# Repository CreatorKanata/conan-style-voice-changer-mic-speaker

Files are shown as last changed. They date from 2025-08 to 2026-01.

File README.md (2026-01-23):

# Conan-Style Voice Changer: Bowtie Mic & Button Speaker

A real-world implementation of the iconic voice changer bowtie from Detective Conan anime.



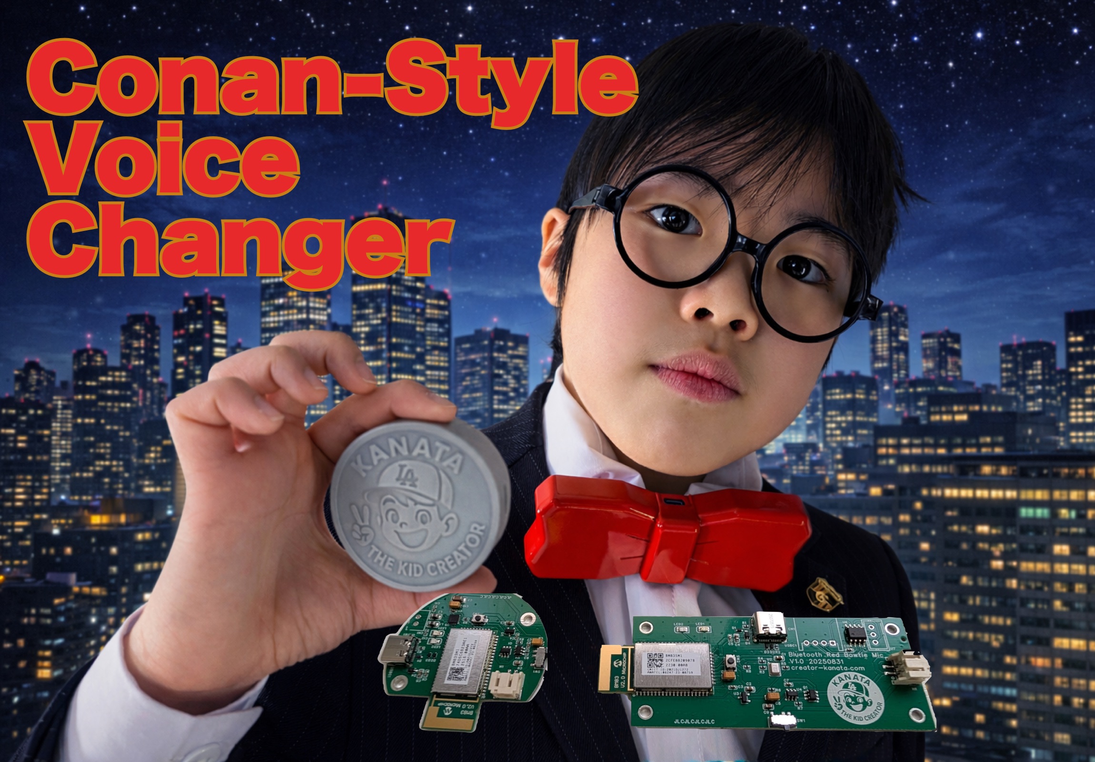
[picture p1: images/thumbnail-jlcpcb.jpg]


### Demo Video

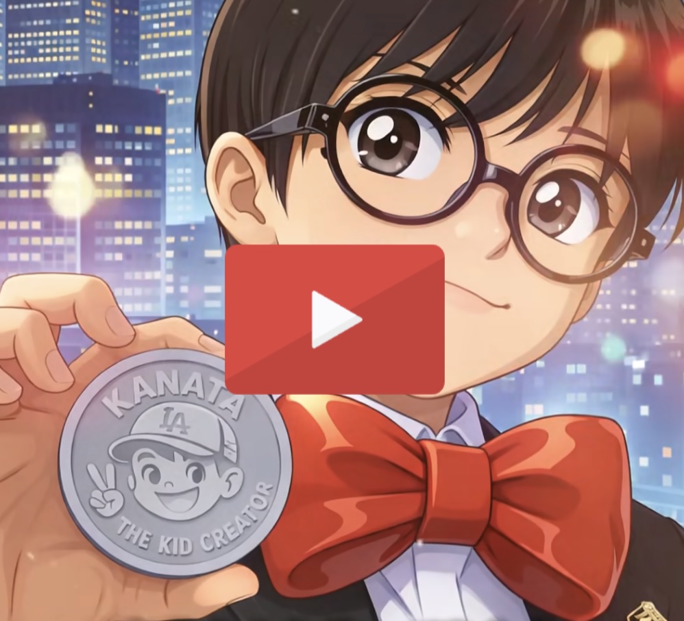
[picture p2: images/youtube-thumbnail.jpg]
Demo Video on YouTube


https://www.youtube.com/shorts/dokzC9MDHtE

### PCB Design on OSHWLab

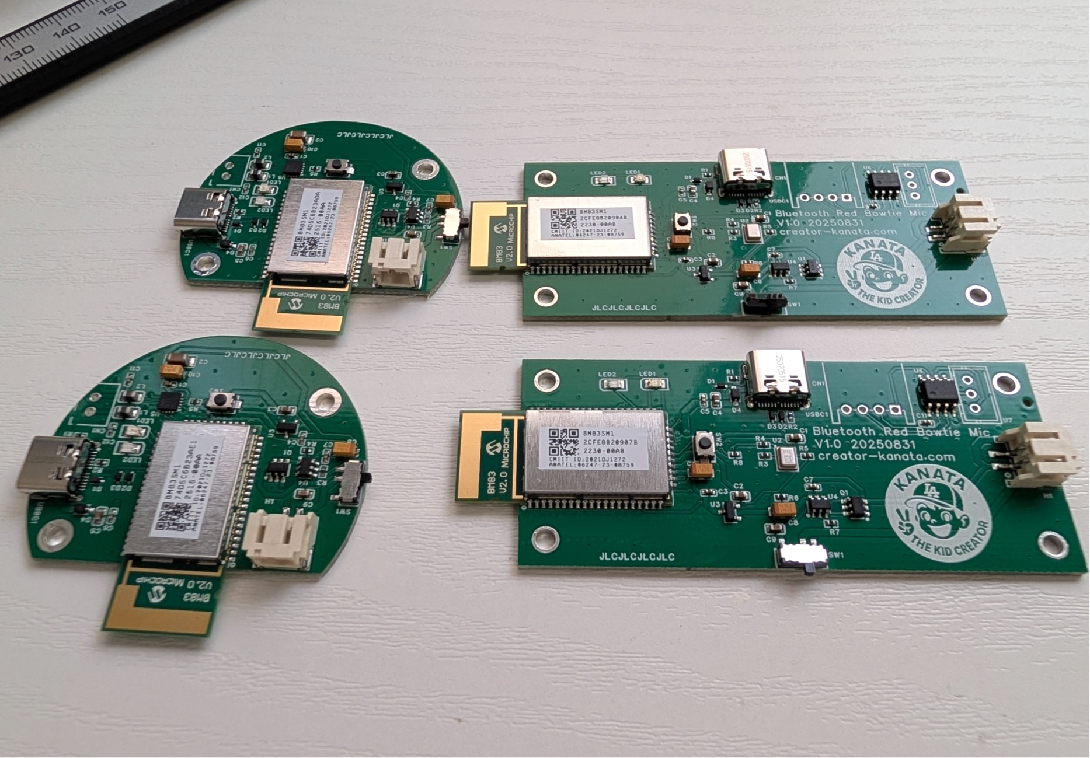
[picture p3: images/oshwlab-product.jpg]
PCB Design on OSHWLab


https://oshwlab.com/creator-kanata/conan-style-mic-speaker

## Overview

This project brings the fictional "voice changer bowtie" from Detective Conan to life. It consists of:

- **Bowtie Microphone**: A wearable microphone in the classic bowtie shape
- **Button Speaker**: A discreet speaker that can be placed anywhere
- **Raspberry Pi 5**: The processing unit that handles voice changing and translation

## Features

- **Real-time Voice Changing** using voice-changer (Beatrice)
- **Japanese to English Translation** using Gemini Live API *(planned)*
- **Wireless Operation** via Bluetooth (HFP for mic, A2DP for speaker)
- **Portable Design** with battery-powered peripherals

## Hardware

### Bowtie Microphone

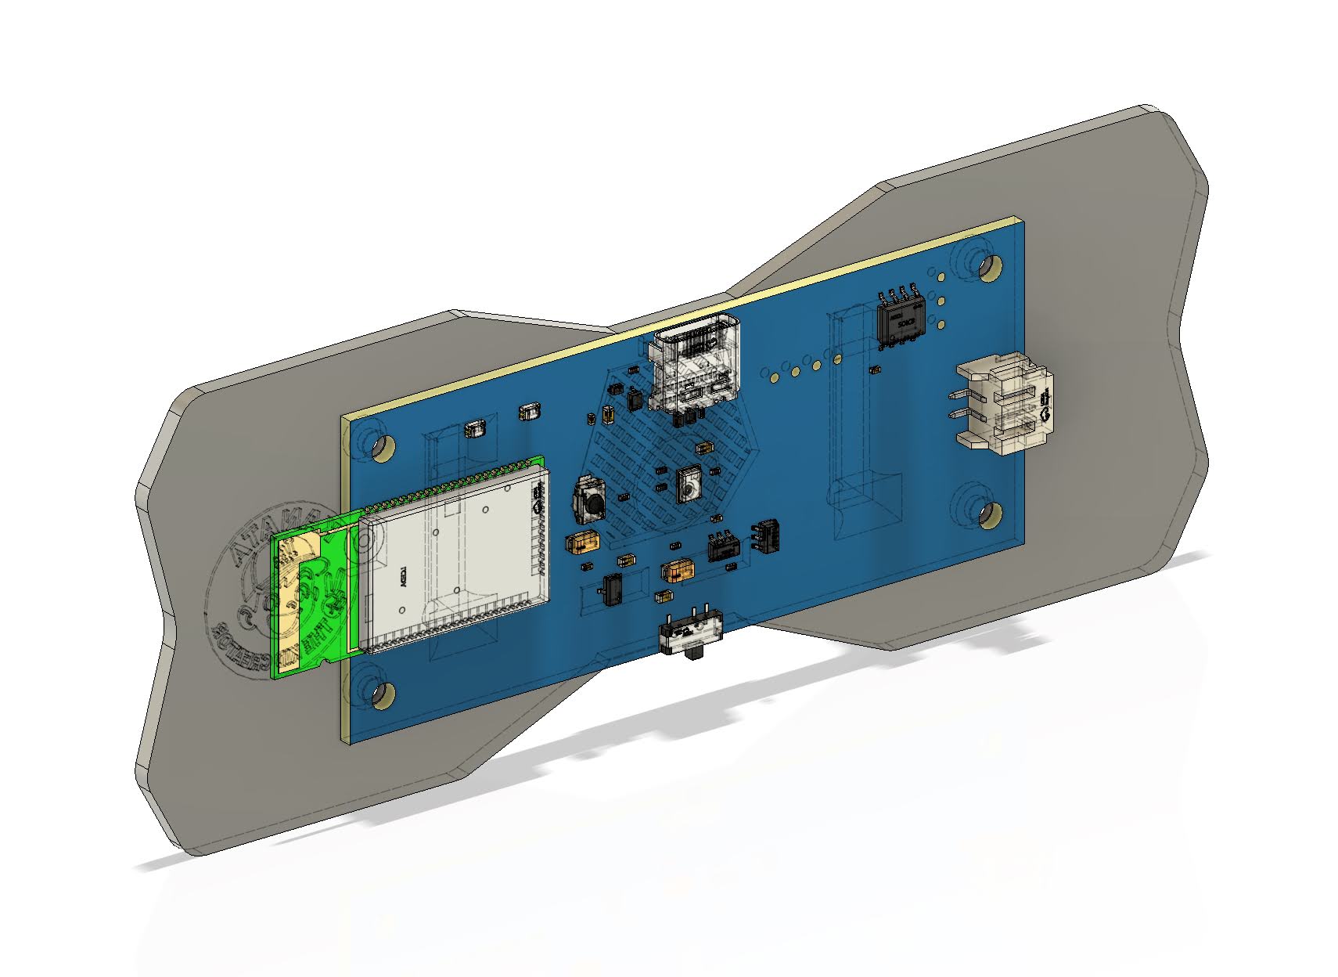
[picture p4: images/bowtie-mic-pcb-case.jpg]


| Component | Description |
|---|---|
| BM83 | Bluetooth audio module (HFP profile) |
| MEMS Mic | High-quality voice capture |
| Battery | Rechargeable LiPo |
| Case | 3D printed bowtie shape |

### Button Speaker

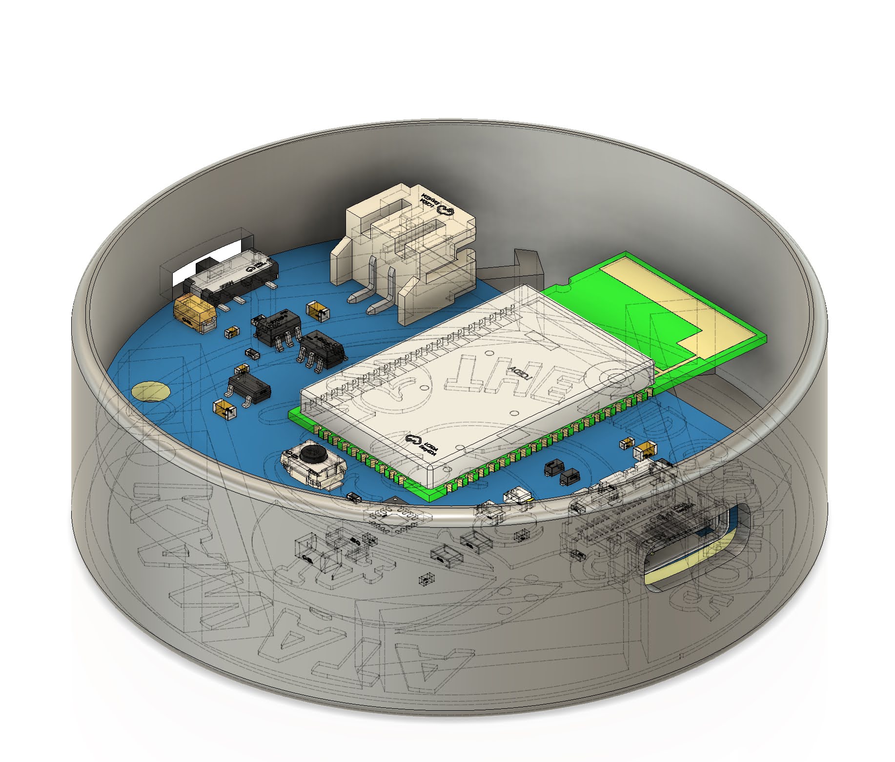
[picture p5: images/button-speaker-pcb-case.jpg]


| Component | Description |
|---|---|
| BM83 | Bluetooth audio module (A2DP profile) |
| Speaker | Thin form factor speaker |
| Battery | Rechargeable LiPo |
| Case | 3D printed button shape |

## Project Structure

```
├── 3d-models/              # 3D printable case designs (STEP)
│   ├── bowtie-mic/         # Bowtie microphone case
│   │   ├── red-bowtie-mic.step
│   │   └── red-bowtie-mic-bottom.step
│   └── button-speaker/     # Button speaker case
│       ├── button-speaker-top.step
│       └── button-speaker-bottom.step
├── pcb/
│   ├── bowtie-mic/         # Microphone PCB (EasyEDA Pro)
│   └── button-speaker/     # Speaker PCB (EasyEDA Pro)
├── raspi5/                 # Raspberry Pi 5 configuration and scripts
└── docs/                   # Documentation
```

## Getting Started

### Hardware Manufacturing

1. **PCB Fabrication**: Upload Gerber files from `pcb/` to [JLCPCB](https://jlcpcb.com)
2. **3D Printing**: Print cases from `3d-models/` (STEP format)
3. **Assembly**: Solder components as per BOM files

### Software Setup (Planned)

See [docs/PLAN.md](docs/PLAN.md) for the detailed implementation plan.

## Documentation

- [Concept](docs/concept.md) - Project vision and architecture
- [Implementation Plan](docs/PLAN.md) - Detailed development roadmap

## Tools Used

| Purpose | Tool |
|---|---|
| PCB Design | EasyEDA Pro |
| 3D Modeling | Autodesk Fusion |
| Voice Processing | Raspberry Pi 5 |
| Voice Changer | [voice-changer (Beatrice)](https://github.com/w-okada/voice-changer) |
| Translation | Gemini Live API |

## Sponsor

3D printing for this project is proudly sponsored by **[JLCPCB](https://jlcpcb.com)**. Thank you for the support!

## License

This project is open source. See LICENSE file for details.

## Acknowledgments

- Inspired by Detective Conan (Case Closed) by Gosho Aoyama
- Built with love for the anime community

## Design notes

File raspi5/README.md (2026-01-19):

## Spec
- Raspberry Pi5 4GB RAM
- SD: 16GB
- OS: Raspberry Pi OS (64-bit) Bookworm 2025-11-24

## Bluetooth audio device

For demonstration at the JLCPCB booth at NEPCON

| Device | MAC Address |
|---|---|
| BUTTON\_SPEAKER (BM83) | `74:D5:C6:B2:3A:DA` |
| RED\_BOWTIE\_MIC (BM83) | `2C:FE:8B:20:90:7B` |

## Installation

### SSH

```
ssh -A kanata@kanan.local
```

### Update

```
sudo apt update
sudo apt upgrade -y
sudo raspi-config
# Localisation Options -> Locale -> Disable en_GB.UTF-8 and Enable en_US.UTF-8
# Localisation Options -> WLAN Country -> JP
sudo reboot
```

```
sudo apt install vim git
git clone git@github.com:CreatorKanata/conan-style-voice-changer-mic-speaker.git
```

Stop GUI (Optional)

```
sudo systemctl set-default multi-user.target
loginctl enable-linger $USER
```

### Enable Bluetooth

```
sudo vi /etc/bluetooth/main.conf
AutoEnable=true

sudo systemctl restart bluetooth
```

```
bluetoothctl
[bluetoothctl]>
```

```
power on
agent on
default-agent
pairable on
discoverable on
scan on
```

Find BUTTON_SPEAKER and RED_BOWTIE_MIC

```
[NEW] Device 74:D5:C6:B2:3A:DA BUTTON_SPEAKER
[NEW] Device 2C:FE:8B:20:90:7B RED_BOWTIE_MIC
```

Pairing

```
scan off
pair 74:D5:C6:B2:3A:DA
trust 74:D5:C6:B2:3A:DA
connect 74:D5:C6:B2:3A:DA
pair 2C:FE:8B:20:90:7B
trust 2C:FE:8B:20:90:7B
connect 2C:FE:8B:20:90:7B
```

### Audio setting

```
wpctl status
PipeWire 'pipewire-0' [1.4.2, kanata@kanan, cookie:1105578633]
 └─ Clients:
        33. WirePlumber                         [1.4.2, kanata@kanan, pid:1307]
        34. pipewire                            [1.4.2, kanata@kanan, pid:1308]
        43. wpctl                               [1.4.2, kanata@kanan, pid:3101]
        47. WirePlumber [export]                [1.4.2, kanata@kanan, pid:1307]
        73. xdg-desktop-portal                  [1.4.2, kanata@kanan, pid:1531]
        74. xdg-desktop-portal-wlr              [1.4.2, kanata@kanan, pid:1593]
        75. unknown                             [1.4.2, kanata@kanan, pid:1474]

Audio
 ├─ Devices:
 │      48. Built-in Audio                      [alsa]
 │      49. Built-in Audio                      [alsa]
 │      76. BUTTON_SPEAKER                      [bluez5]
 │  
 ├─ Sinks:
 │  *   77. BUTTON_SPEAKER                      [vol: 0.40]
 │  
 ├─ Sources:
 │  
 ├─ Filters:
 │  
 └─ Streams:

Video
 ├─ Devices:
 │      56. rpi-hevc-dec                        [v4l2]
 │      57. pispbe                              [v4l2]
 │      58. pispbe                              [v4l2]
 │      59. pispbe                              [v4l2]
 │      60. pispbe                              [v4l2]
 │      61. pispbe                              [v4l2]
 │      62. pispbe                              [v4l2]
 │      63. pispbe                              [v4l2]
 │      64. pispbe                              [v4l2]
 │      65. pispbe                              [v4l2]
 │      66. pispbe                              [v4l2]
 │      67. pispbe                              [v4l2]
 │      68. pispbe                              [v4l2]
 │      69. pispbe                              [v4l2]
 │      70. pispbe                              [v4l2]
 │      71. pispbe                              [v4l2]
 │      72. pispbe                              [v4l2]
 │  
 ├─ Sinks:
 │  
 ├─ Sources:
 │  
 ├─ Filters:
 │  
 └─ Streams:

Settings
 └─ Default Configured Devices:

```

Test Speaker

```
wpctl set-volume @DEFAULT_AUDIO_SINK@ 1.0
wpctl set-volume @DEFAULT_AUDIO_SINK@ 0.3
pw-play ~/conan-style-voice-changer-mic-speaker/raspi5/sounds/test_sp.wav 
```

```
mkdir -p ~/.local/bin

cp ~/conan-style-voice-changer-mic-speaker/raspi5/local/ensure-audio-defaults.sh ~/.local/bin/
chmod 755 ~/.local/bin/ensure-audio-defaults.sh

cp ~/conan-style-voice-changer-mic-speaker/raspi5/local/wait-for-audio-devices.sh ~/.local/bin/
chmod 755 ~/.local/bin/wait-for-audio-devices.sh 

cp ~/conan-style-voice-changer-mic-speaker/raspi5/local/vcclient-autostart.sh ~/.local/bin/
chmod 755 ~/.local/bin/vcclient-autostart.sh
```

```
mkdir -p ~/.config/systemd/user
cp ~/conan-style-voice-changer-mic-speaker/raspi5/local/ensure-audio-defaults.service ~/.config/systemd/user/
cp ~/conan-style-voice-changer-mic-speaker/raspi5/local/vcclient.service ~/.config/systemd/user/

systemctl --user daemon-reload
systemctl --user enable --now ensure-audio-defaults.service
systemctl --user enable --now vcclient.service

systemctl --user restart ensure-audio-defaults.service
systemctl --user status ensure-audio-defaults.service

systemctl --user restart vcclient.service
systemctl --user status vcclient.service

```

## Download Beatrice vcclient for aarch64

```
mkdir vcclient
cd vcclient
wget https://huggingface.co/wok000/vcclient000/resolve/main/vcclient_std_lin_aarch64_2.2.2-beta_only_beatrice.zip
unzip vcclient_std_lin_aarch64_2.2.2-beta_only_beatrice.zip
cd dist

sudo apt install -y libportaudio2 portaudio19-dev libasound2 libasound2-dev libayatana-appindicator3-1 libappindicator3-1

./start_https.sh
```

---

### API

Start API

```
cd ~/vcclient/dist
./start_http.sh
```

Start voice changer

```
2026-01-20 02:57:20,221 - uvicorn.ac - h11_impl             - INFO - 192.168.31.81:51223 - "POST /api/local-voice-changer-interface/operation/start HTTP/1.1" 200 - uvicorn/protocols/http/h11_impl.py - 473
```

Change voice character

```
2026-01-20 02:58:56,232 - uvicorn.ac - h11_impl             - INFO - 192.168.31.81:51282 - "PUT /api/slot-manager/slots/0 HTTP/1.1" 200 - uvicorn/protocols/http/h11_impl.py - 473
```

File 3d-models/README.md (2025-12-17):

# 3D Models

3D printable case designs for the Conan-style voice changer project. All models are designed with [Autodesk Fusion](https://www.autodesk.com/products/fusion-360/).

## Bowtie Microphone Case

A classic red bowtie-shaped case housing the BM83 Bluetooth module, MEMS microphone, and battery.

### Assembly Preview

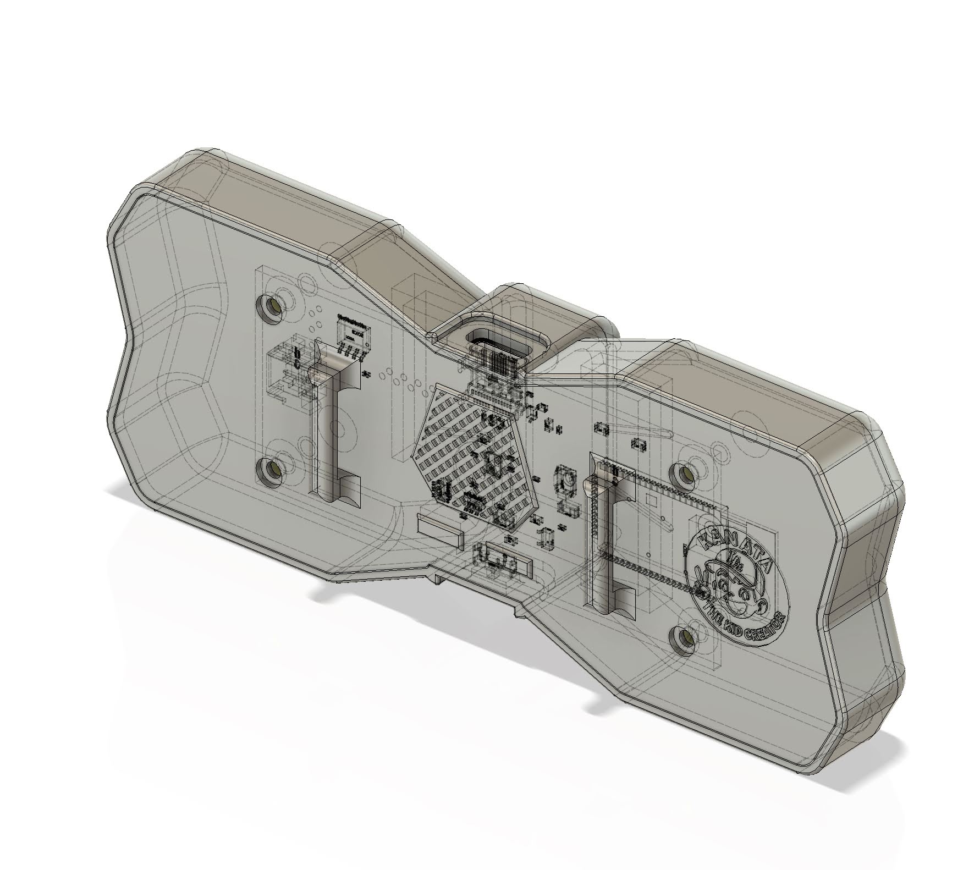
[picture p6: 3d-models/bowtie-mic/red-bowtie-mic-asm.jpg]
Bowtie Mic Assembly


### Parts

| File | Description |
|---|---|
| `red-bowtie-mic.step` | Top shell (red bowtie shape) |
| `red-bowtie-mic-bottom.step` | Bottom cover |

### Components Inside

- BM83 Bluetooth module PCB
- MEMS microphone
- LiPo battery
- Power switch

---

## Button Speaker Case

A compact circular button-shaped case for the speaker unit.

### Assembly Preview

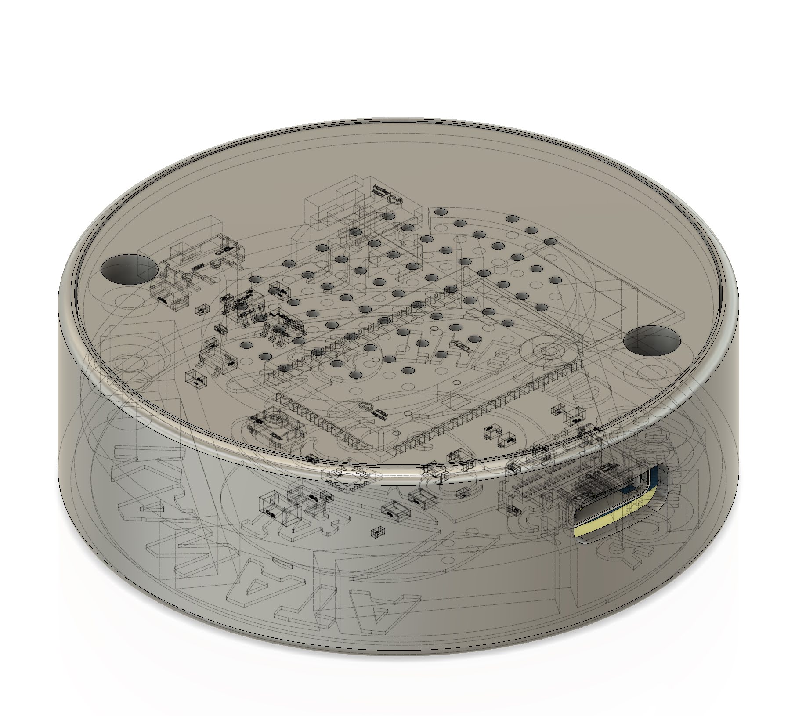
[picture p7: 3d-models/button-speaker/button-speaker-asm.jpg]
Button Speaker Assembly


### Parts

| File | Description |
|---|---|
| `button-speaker-top.step` | Top cover with speaker grill |
| `button-speaker-bottom.step` | Bottom shell |

### Components Inside

- BM83 Bluetooth module PCB
- Thin speaker driver
- LiPo battery
- Power switch

---

## Printing Recommendations

| Parameter | Recommendation |
|---|---|
| Material | PLA or PETG |
| Layer Height | 0.2mm |
| Infill | 20-30% |
| Supports | May be needed for overhangs |

## Sponsor

3D printing for this project is sponsored by **[JLCPCB](https://jlcpcb.com)**. Thank you!

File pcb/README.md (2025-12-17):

# PCB Designs

Custom PCB designs for the Conan-style voice changer project. All boards are designed with [EasyEDA Pro](https://pro.easyeda.com/) for easy ordering from JLCPCB.

## Bowtie Microphone

Bluetooth microphone board with BM83 module and MEMS microphone.

### Features

- BM83 Bluetooth module (HFP profile)
- MEMS microphone for high-quality voice capture
- Battery charging circuit
- Compact form factor to fit in bowtie case

### Board Preview

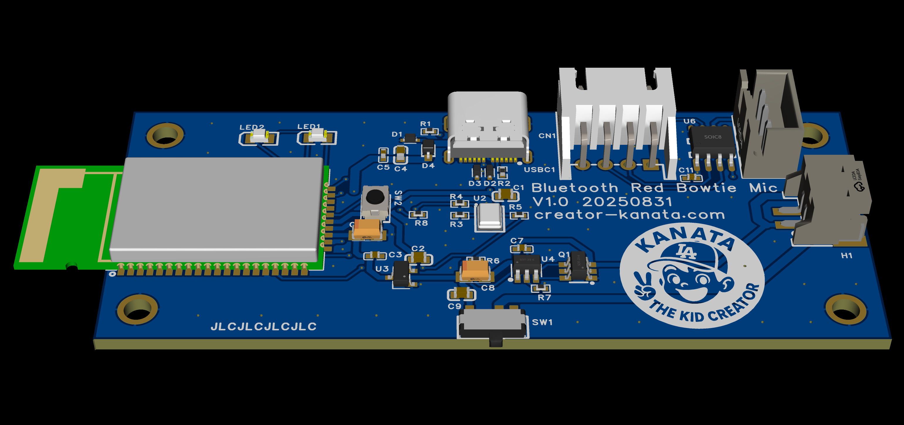
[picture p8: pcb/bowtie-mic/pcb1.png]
Bowtie Mic PCB


### PCBA Preview

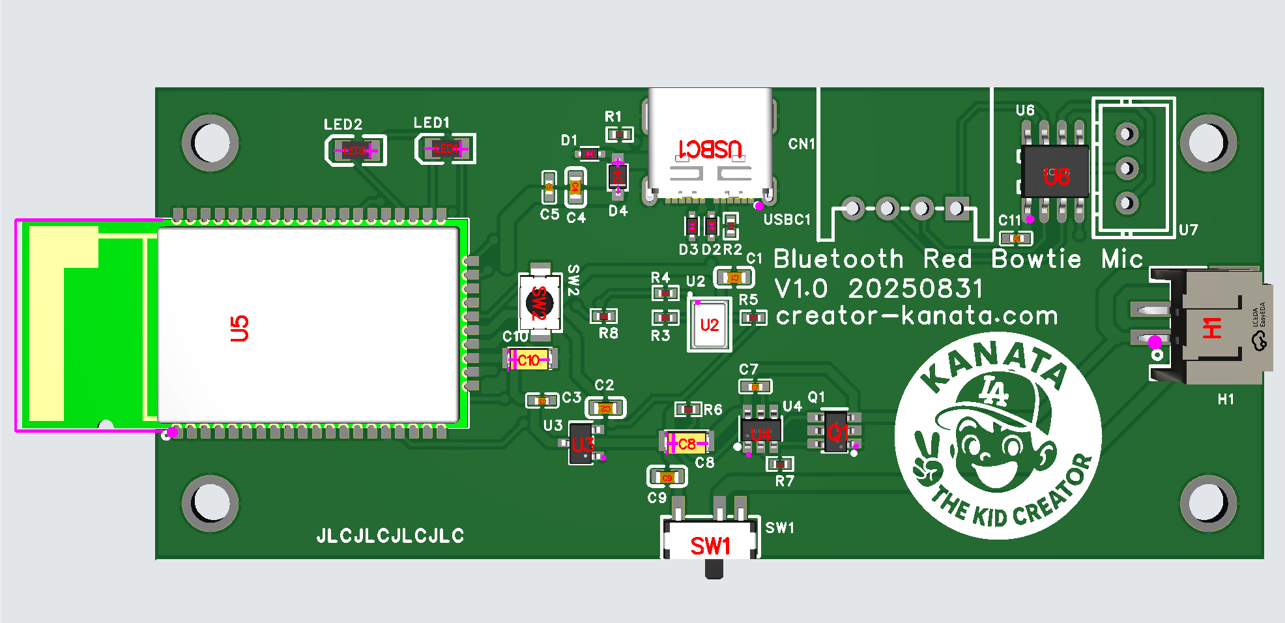
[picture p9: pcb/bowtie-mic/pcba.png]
Bowtie Mic PCBA


### Files

| File | Description |
|---|---|
| `Gerber_*.zip` | Gerber files for PCB fabrication |
| `BOM_*.xlsx` | Bill of Materials |
| `PickAndPlace_*.xlsx` | Pick and place file for SMT assembly |
| `3D_*.step` | 3D model of the board |
| `SCH_*.pdf` | Schematic diagram |

---

## Button Speaker

Bluetooth speaker board with BM83 module.

### Features

- BM83 Bluetooth module (A2DP profile)
- Thin speaker driver circuit
- Battery charging circuit
- Compact circular design for button case

### Board Preview

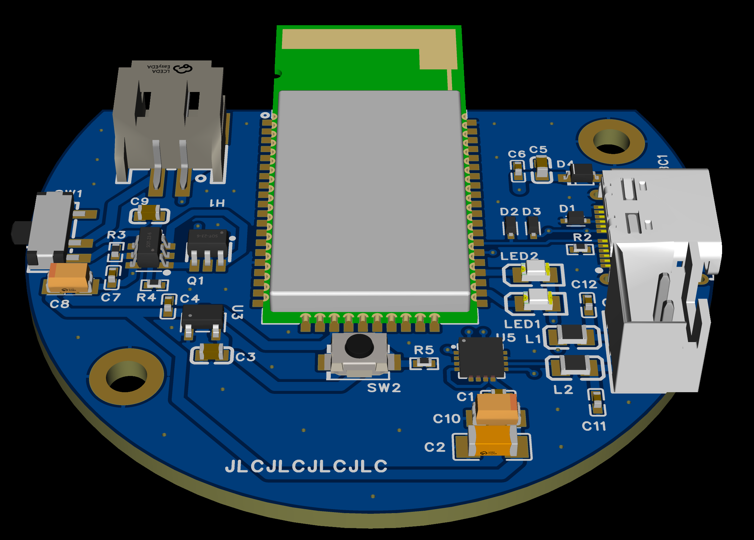
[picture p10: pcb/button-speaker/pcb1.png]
Button Speaker PCB Front


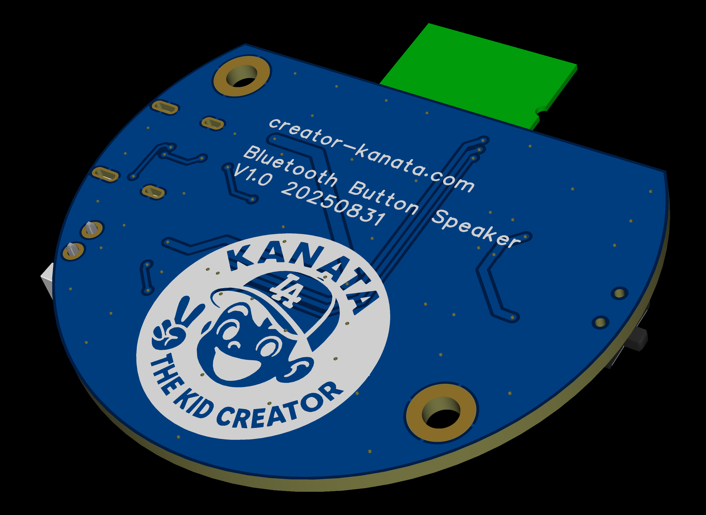
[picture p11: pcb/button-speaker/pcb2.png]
Button Speaker PCB Back


### PCBA Preview

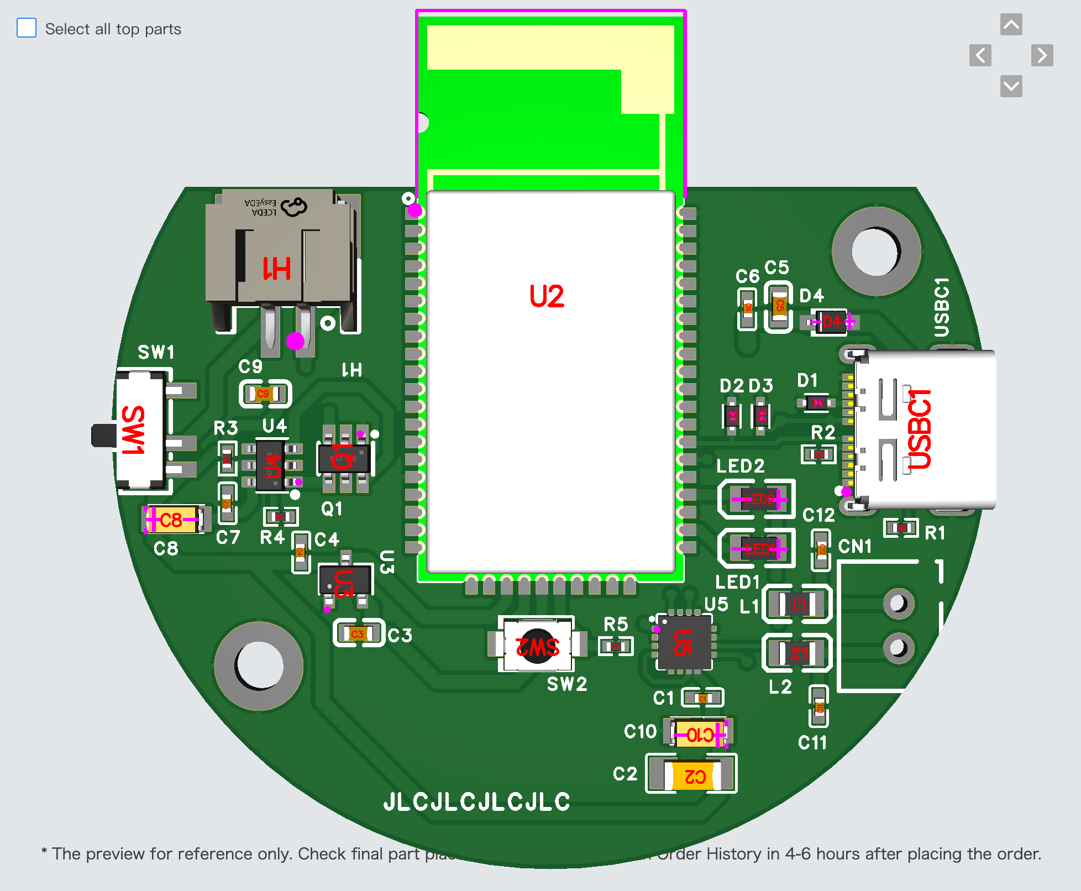
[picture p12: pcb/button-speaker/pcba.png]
Button Speaker PCBA


### Files

| File | Description |
|---|---|
| `Gerber_*.zip` | Gerber files for PCB fabrication |
| `BOM_*.xlsx` | Bill of Materials |
| `PickAndPlace_*.xlsx` | Pick and place file for SMT assembly |
| `3D_*.step` | 3D model of the board |
| `SCH_*.pdf` | Schematic diagram |

---

## Manufacturing

All PCBs are designed for manufacturing at [JLCPCB](https://jlcpcb.com).

### Ordering Steps

1. Go to [JLCPCB](https://jlcpcb.com)
2. Upload the Gerber ZIP file
3. Select PCB options (color, thickness, etc.)
4. Enable SMT Assembly if needed
5. Upload BOM and Pick-and-Place files for assembly
6. Place order

## Sponsor

PCB manufacturing for this project is sponsored by **JLCPCB**. Thank you!

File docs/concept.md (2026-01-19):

# Project Concept

## Vision

Bring the iconic voice changer bowtie from Detective Conan anime to reality. This device allows the user to speak into a bowtie-shaped microphone and have their transformed voice emitted from a button-shaped speaker placed elsewhere.

## Inspiration

In the Detective Conan manga and anime series, the protagonist uses a "bowtie voice changer" invented by Dr. Agasa. The device allows him to mimic any voice by speaking into a bowtie-shaped microphone, with the modified voice coming out of a speaker placed near the target.

This project aims to create a functional real-world version of this fictional device.

## System Architecture

```
┌─────────────────────┐     Bluetooth HFP     ┌──────────────────────┐
│   Bowtie Mic        │◄────────────────────►│                      │
│   - BM83 Module     │                       │   Raspberry Pi 5     │
│   - MEMS Microphone │                       │                      │
│   - Battery         │                       │   - Voice Changer    │
│   - 3D Printed Case │                       │     (Beatrice)       │
└─────────────────────┘                       │                      │
                                              │   - Real-time        │
┌─────────────────────┐     Bluetooth A2DP    │     Translation      │
│   Button Speaker    │◄────────────────────►│     (Gemini Live)    │
│   - BM83 Module     │                       │                      │
│   - Thin Speaker    │                       └──────────────────────┘
│   - Battery         │
│   - 3D Printed Case │
└─────────────────────┘
```

## Hardware Design Philosophy

### Bowtie Microphone

- **Form Factor**: Classic bowtie shape to match the original anime design
- **Wireless**: Bluetooth HFP profile for bidirectional audio
- **Portable**: Battery-powered for wearable use
- **Audio Quality**: MEMS microphone for clear voice capture

### Button Speaker

- **Discreet**: Small button shape that can be hidden or placed strategically
- **High Quality Output**: Thin but capable speaker for clear voice reproduction
- **Wireless**: Bluetooth A2DP profile for high-quality audio streaming
- **Portable**: Battery-powered for flexible placement

### Why BM83?

The Microchip BM83 Bluetooth module was chosen for:
- Dual-mode Bluetooth (Classic + BLE)
- Support for HFP and A2DP profiles
- Low power consumption
- Compact form factor
- Built-in audio codec

## Software Features

### Voice Changer (Beatrice)

voice-changer (Beatrice) enables real-time voice transformation:
- Pre-trained voice models available
- Real-time inference on Raspberry Pi 5 CPU
- Low latency processing for natural conversation

### Real-time Translation (Gemini Live API)

Japanese to English translation using Google's Gemini Live API:
- Speech-to-text in Japanese
- Real-time translation
- Text-to-speech in English (with voice changer applied)

## Use Cases

1. **Cosplay**: Authentic Detective Conan cosplay with functional props
2. **Entertainment**: Fun voice changing for parties and events
3. **Accessibility**: Potential applications for speech assistance
4. **Translation**: Real-time Japanese to English interpretation

## Challenges

1. **Latency**: Minimizing delay between input and output for natural feel
2. **Audio Quality**: Balancing compact design with good sound quality
3. **Battery Life**: Optimizing power consumption for extended use
4. **Bluetooth Stability**: Ensuring reliable connection between devices

## Future Enhancements

- Multiple voice presets
- Mobile app for control and configuration
- Two-way translation support
- Voice cloning from short samples
- Improved battery life and charging solutions

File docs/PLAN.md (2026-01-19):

# Implementation Plan

## Current Status

### Completed

- [x] Bowtie microphone PCB design (BM83 + MEMS mic)
- [x] Button speaker PCB design (BM83 + speaker)
- [x] 3D case design for bowtie microphone
- [x] 3D case design for button speaker
- [x] Schematic documentation (PDF)

### In Progress

- [x] Raspberry Pi 5 setup and configuration
- [x] Voice changer implementation (Beatrice)
- [ ] Real-time translation implementation (Gemini Live API)

## Implementation Steps

### Phase 1: Raspberry Pi 5 Environment Setup

#### 1.1 System Configuration

- [x] Install Raspberry Pi OS (64-bit) Bookworm
- [x] Configure system locale and WLAN
- [x] Install required packages

#### 1.2 Bluetooth Audio Setup

- [x] Configure PipeWire for Bluetooth
- [x] Pair BM83 microphone (HFP profile)
- [x] Pair BM83 speaker (A2DP profile)
- [x] Configure audio routing (mic input → processing → speaker output)
- [x] Test Bluetooth auto-reconnection on boot

#### 1.3 Audio Pipeline

- [x] Set up audio capture from HFP source
- [x] Configure sample rate and buffer settings for low latency
- [x] Set up audio output to A2DP sink
- [x] Test end-to-end audio passthrough

### Phase 2: Voice Changer (Beatrice)

#### 2.1 voice-changer Setup

- [x] Download voice-changer (vcclient) for aarch64
- [x] Install required dependencies
- [x] Test basic voice conversion

#### 2.2 Real-time Processing

- [x] Configure voice-changer for real-time inference
- [x] Optimize buffer sizes for minimum latency
- [x] Implement voice model switching via API

#### 2.3 Integration

- [x] Connect Bluetooth input to voice-changer
- [x] Connect voice-changer output to Bluetooth speaker
- [x] Test end-to-end voice changing
- [ ] Measure and optimize latency

### Phase 3: Real-time Translation

#### 3.1 Gemini Live API Setup

- [ ] Set up Google Cloud credentials
- [ ] Implement Gemini Live API client
- [ ] Test speech-to-text in Japanese
- [ ] Test translation to English

#### 3.2 Text-to-Speech Integration

- [ ] Implement TTS for translated text
- [ ] Integrate with voice changer for consistent output
- [ ] Test end-to-end translation pipeline

#### 3.3 Mode Switching

- [ ] Implement mode selection (voice change only / translation)
- [ ] Add physical button or gesture control (optional)
- [ ] Create configuration interface

### Phase 4: System Integration

#### 4.1 Startup and Auto-run

- [x] Create systemd service for voice changer
- [x] Configure auto-start on boot
- [x] Implement graceful shutdown handling
- [x] Add logging and monitoring

#### 4.2 Power Management

- [ ] Optimize for power efficiency
- [ ] Implement sleep/wake functionality
- [ ] Battery monitoring for peripherals (future)

#### 4.3 Testing and Refinement

- [ ] End-to-end testing with all components
- [ ] Latency measurement and optimization
- [ ] User experience testing
- [ ] Bug fixes and stability improvements

## Directory Structure

```
raspi5/
├── local/
│   ├── ensure-audio-defaults.sh    # Audio device monitoring script
│   ├── ensure-audio-defaults.service
│   ├── wait-for-audio-devices.sh   # Wait for BT devices script
│   ├── vcclient-autostart.sh       # Voice changer auto-start script
│   └── vcclient.service            # Systemd service file
├── sounds/
│   ├── test_sp.wav                 # Speaker test sound
│   ├── test_mic.wav                # Microphone test sound
│   └── start.wav                   # Startup sound
└── README.md                       # Setup instructions
```

## Technical Specifications

### Audio Pipeline

- Sample Rate: 16kHz for speech processing, 48kHz for output
- Buffer Size: ~20-40ms for low latency
- Format: PCM 16-bit

### Latency Targets

- Voice Changer: < 100ms end-to-end
- Translation: < 500ms for real-time feel

### Hardware Requirements

- Raspberry Pi 5 (4GB RAM)
- BM83 Bluetooth modules (pre-paired)
- Stable power supply
- SD card (16GB+)

## Dependencies

### voice-changer (vcclient)

- Download from: https://github.com/w-okada/voice-changer
- Use aarch64 version with Beatrice support

### System Packages

- PipeWire (audio server)
- BlueZ (Bluetooth stack)
- libportaudio2, portaudio19-dev
- libasound2, libasound2-dev
- libayatana-appindicator3-1, libappindicator3-1

## Risks and Mitigations

| Risk | Mitigation |
|---|---|
| High latency | Optimize buffer sizes, use Beatrice (CPU-optimized) |
| Bluetooth instability | Implement reconnection logic with systemd services |
| CPU constraints | Use Beatrice model optimized for ARM |
| Power consumption | Use efficient inference settings |

## Success Criteria

1. Voice changing works with < 100ms latency
2. Translation mode provides usable real-time output
3. System starts automatically and runs stably
4. Bluetooth devices reconnect automatically
5. Audio quality is clear and intelligible

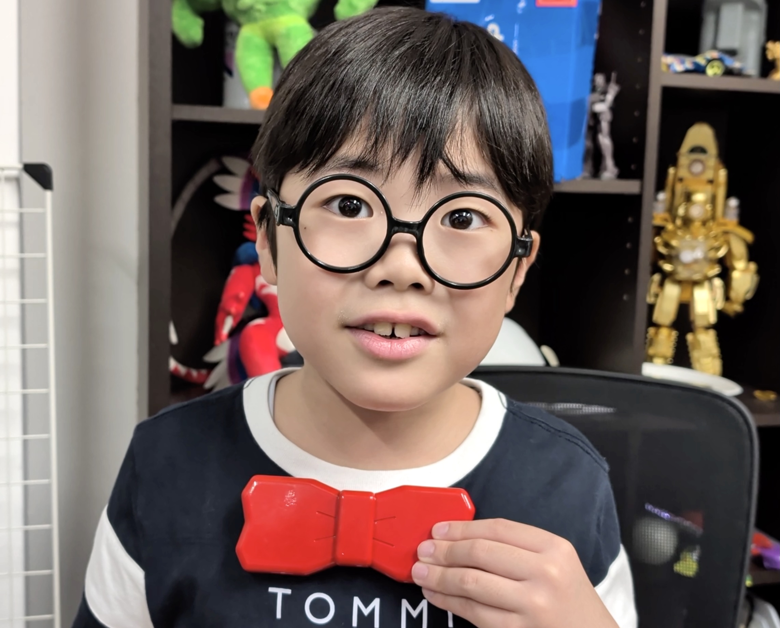
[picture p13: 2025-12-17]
images/hero.jpg

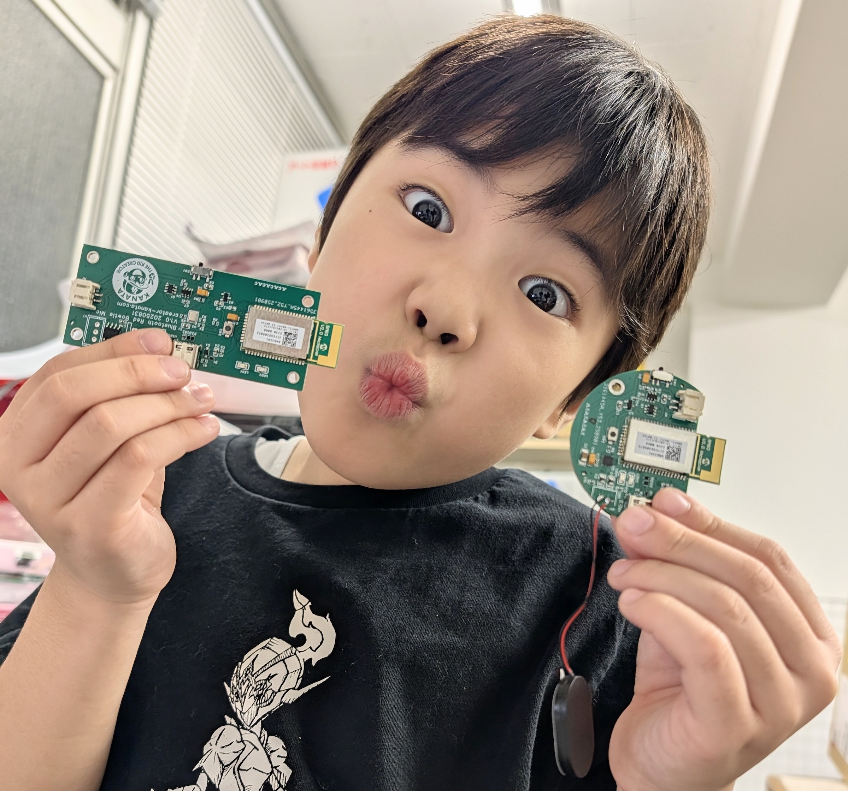
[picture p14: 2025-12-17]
images/mic-speaker-pcb.jpg

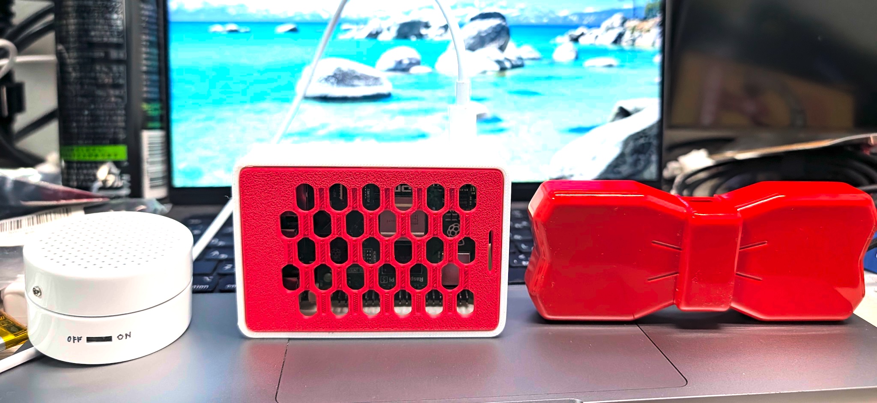
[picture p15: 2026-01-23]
images/oshwlab-hero.jpg

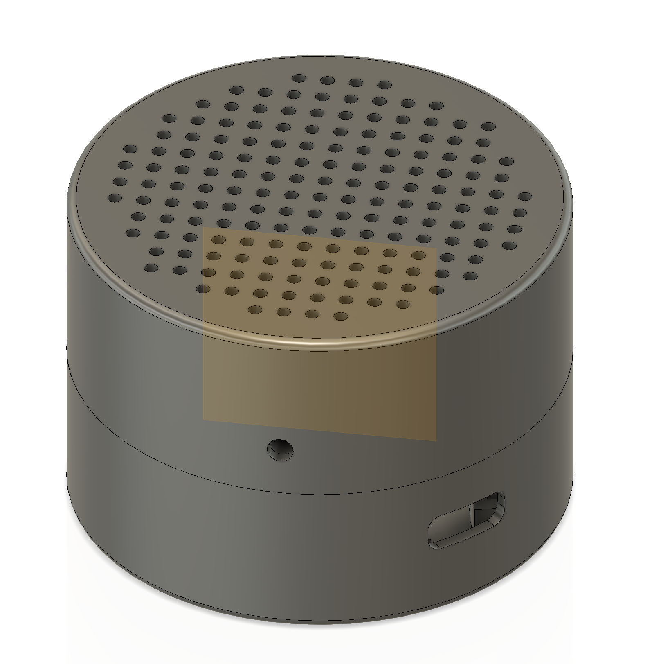
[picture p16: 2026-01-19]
pcb/button-speaker/big-speaker-version.png

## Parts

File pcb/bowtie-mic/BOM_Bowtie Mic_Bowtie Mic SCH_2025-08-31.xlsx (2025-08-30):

No. | Quantity | Comment | Designator | Footprint | Value | Manufacturer Part | Manufacturer | Supplier Part | Supplier
1 | 3 | 1uF | C1,C2,C4 | C0603 | 1uF | CL10A105KO8NNNC | SAMSUNG(三星) | C1592 | LCSC
2 | 4 | 100nF | C3,C5,C7,C11 | C0402 | 100nF | CL05B104KO5NNNC | SAMSUNG(三星) | C1525 | LCSC
3 | 2 | 47uF | C8,C10 | CASE-A_3216 | 47uF | TAJA476K006RNJ | Kyocera AVX | C7190 | LCSC
4 | 1 | 4.7uF | C9 | C0603 | 4.7uF | CL10A475KP8NNNC | SAMSUNG(三星) | C1705 | LCSC
5 | 3 | LESD5D5.0CT1G | D1,D2,D3 | SOD-523_L1.2-W0.8-LS1.6-BI |  | LESD5D5.0CT1G | UMW(友台半导体) | C5199850 | LCSC
6 | 1 | 1N5819WS | D4 | SOD-323_L1.8-W1.3-LS2.5-RD |  | 1N5819WS | PJSEMI(平晶微) | C440261 | LCSC
7 | 1 | WAFER-PH2.0-2PWB | H1 | CONN-SMD_2P-P2.00_XUNPU_WAFER-PH2.0-2PWB |  | WAFER-PH2.0-2PWB | XUNPU(讯普) | C3029440 | LCSC
8 | 1 | NCD0805R1 | LED1 | LED0805-R-RD |  | NCD0805R1 | 国星光电 | C84256 | LCSC
9 | 1 | KT-0805G | LED2 | LED0805-R-RD |  | KT-0805G | KENTO | C2297 | LCSC
10 | 1 | FS8205A | Q1 | SOT-23-6_L2.9-W1.6-P0.95-LS2.8-BR |  | FS8205A | TECH PUBLIC(台舟) | C2830320 | LCSC
11 | 2 | 5.1kΩ | R1,R2 | R0402 | 5.1kΩ | 0402WGF5101TCE | UNI-ROYAL(厚声) | C25905 | LCSC
12 | 2 | 100kΩ | R3,R8 | R0402 | 100kΩ | 0402WGF1003TCE | UNI-ROYAL(厚声) | C25741 | LCSC
13 | 2 | 22Ω | R4,R5 | R0402 | 22Ω | 0402WGF220JTCE | UNI-ROYAL(厚声) | C25092 | LCSC
14 | 1 | 470Ω | R6 | R0402 | 470Ω | 0402WGF4700TCE | UNI-ROYAL(厚声) | C25117 | LCSC
15 | 1 | 1kΩ | R7 | R0402 | 1kΩ | 0402WGF1001TCE | UNI-ROYAL(厚声) | C11702 | LCSC
16 | 1 | SSSS810701 | SW1 | SW-SMD_SSSS810701 |  | SSSS810701 | ALPSALPINE(阿尔卑斯阿尔派) | C97433 | LCSC
17 | 1 | TS-1088-AR02016 | SW2 | SW-SMD_L3.9-W3.0-P4.45 |  | TS-1088-AR02016 | XUNPU(讯普) | C720477 | LCSC
18 | 1 | SD18OB261-060 | U2 | MIC-SMD_SD18OB261-060 |  | SD18OB261-060 | Goertek(歌尔) | C2895290 | LCSC
19 | 1 | XC6206P332MR | U3 | SOT-23-3_L3.0-W1.7-P0.95-LS2.9-BR |  | XC6206P332MR | UMW(友台半导体) | C347376 | LCSC
20 | 1 | DW01A | U4 | SOT-23-6_L2.9-W1.6-P0.95-LS2.8-BL |  | DW01A | YONGYUTAI(永裕泰) | C2927799 | LCSC
21 | 1 | BM83SM1-00AB | U5 | COMM-SMD_BM83SM1 |  | BM83SM1-00AB | MICROCHIP(美国微芯) | C1019375 | LCSC
22 | 1 | ATTINY202-SSNR | U6 | SOIC-8_L5.0-W4.0-P1.27-LS6.0-BL |  | ATTINY202-SSNR | MICROCHIP(美国微芯) | C2052951 | LCSC
23 | 1 | 1054500101 | USBC1 | USB-C-SMD_TYPE-C-USB-18 |  | 1054500101 | MOLEX | C134092 | LCSC

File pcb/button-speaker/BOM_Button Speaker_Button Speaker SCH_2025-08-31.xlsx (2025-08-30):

No. | Quantity | Comment | Designator | Footprint | Value | Manufacturer Part | Manufacturer | Supplier Part | Supplier
1 | 4 | 100nF | C1,C4,C6,C7 | C0402 | 100nF | CL05B104KO5NNNC | SAMSUNG(三星) | C1525 | LCSC
2 | 1 | 10uF | C2 | C1206 | 10uF | CL31A106KBHNNNE | SAMSUNG(三星) | C13585 | LCSC
3 | 2 | 1uF | C3,C5 | C0603 | 1uF | CL10A105KO8NNNC | SAMSUNG(三星) | C1592 | LCSC
4 | 2 | 47uF | C8,C10 | CASE-A_3216 | 47uF | TAJA476K006RNJ | Kyocera AVX | C7190 | LCSC
5 | 1 | 4.7uF | C9 | C0603 | 4.7uF | CL10A475KP8NNNC | SAMSUNG(三星) | C1705 | LCSC
6 | 2 | 470pF | C11,C12 | C0402 | 470pF | 0402CG471J500NT | FH(风华) | C75274 | LCSC
7 | 3 | LESD5D5.0CT1G | D1,D2,D3 | SOD-523_L1.2-W0.8-LS1.6-BI |  | LESD5D5.0CT1G | UMW(友台半导体) | C5199850 | LCSC
8 | 1 | 1N5819WS | D4 | SOD-323_L1.8-W1.3-LS2.5-RD |  | 1N5819WS | PJSEMI(平晶微) | C440261 | LCSC
9 | 1 | WAFER-PH2.0-2PWB | H1 | CONN-SMD_2P-P2.00_XUNPU_WAFER-PH2.0-2PWB |  | WAFER-PH2.0-2PWB | XUNPU(讯普) | C3029440 | LCSC
10 | 2 | 100uH | L1,L2 | L0805 | 100uH | MLF2012C101KT000 | TDK | C68035 | LCSC
11 | 1 | NCD0805R1 | LED1 | LED0805-R-RD |  | NCD0805R1 | 国星光电 | C84256 | LCSC
12 | 1 | KT-0805G | LED2 | LED0805-R-RD |  | KT-0805G | KENTO | C2297 | LCSC
13 | 1 | FS8205A | Q1 | SOT-23-6_L2.9-W1.6-P0.95-LS2.8-BR |  | FS8205A | TECH PUBLIC(台舟) | C2830320 | LCSC
14 | 2 | 5.1kΩ | R1,R2 | R0402 | 5.1kΩ | 0402WGF5101TCE | UNI-ROYAL(厚声) | C25905 | LCSC
15 | 1 | 470Ω | R3 | R0402 | 470Ω | 0402WGF4700TCE | UNI-ROYAL(厚声) | C25117 | LCSC
16 | 1 | 1kΩ | R4 | R0402 | 1kΩ | 0402WGF1001TCE | UNI-ROYAL(厚声) | C11702 | LCSC
17 | 1 | 100kΩ | R5 | R0402 | 100kΩ | 0402WGF1003TCE | UNI-ROYAL(厚声) | C25741 | LCSC
18 | 1 | SSSS810701 | SW1 | SW-SMD_SSSS810701 |  | SSSS810701 | ALPSALPINE(阿尔卑斯阿尔派) | C97433 | LCSC
19 | 1 | TS-1088-AR02016 | SW2 | SW-SMD_L3.9-W3.0-P4.45 |  | TS-1088-AR02016 | XUNPU(讯普) | C720477 | LCSC
20 | 1 | BM83SM1-00AB | U2 | COMM-SMD_BM83SM1 |  | BM83SM1-00AB | MICROCHIP(美国微芯) | C1019375 | LCSC
21 | 1 | XC6206P332MR | U3 | SOT-23-3_L3.0-W1.7-P0.95-LS2.9-BR |  | XC6206P332MR | UMW(友台半导体) | C347376 | LCSC
22 | 1 | DW01A | U4 | SOT-23-6_L2.9-W1.6-P0.95-LS2.8-BL |  | DW01A | YONGYUTAI(永裕泰) | C2927799 | LCSC
23 | 1 | MAX98357AETE+T | U5 | TQFN-16_L3.0-W3.0-P0.50-BL-EP1.5 |  | MAX98357AETE+T | ADI(亚德诺)/MAXIM(美信) | C910544 | LCSC
24 | 1 | 1054500101 | USBC1 | USB-C-SMD_TYPE-C-USB-18 |  | 1054500101 | MOLEX | C134092 | LCSC

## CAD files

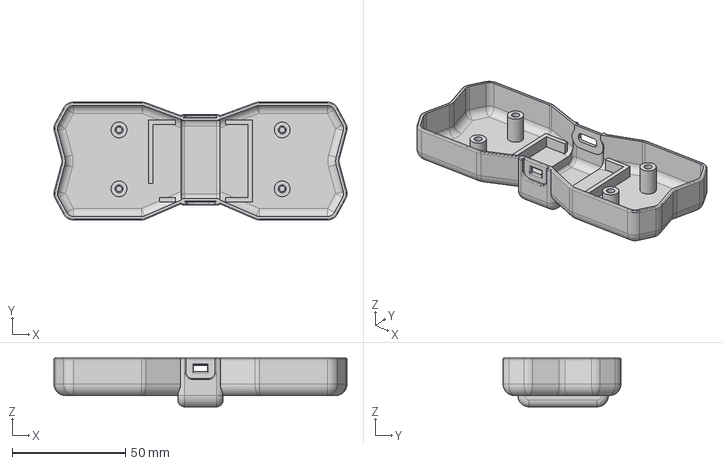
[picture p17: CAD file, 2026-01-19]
3d-models/bowtie-mic/red-bowtie-mic.step
129.3 x 52.0 x 21.5 mm

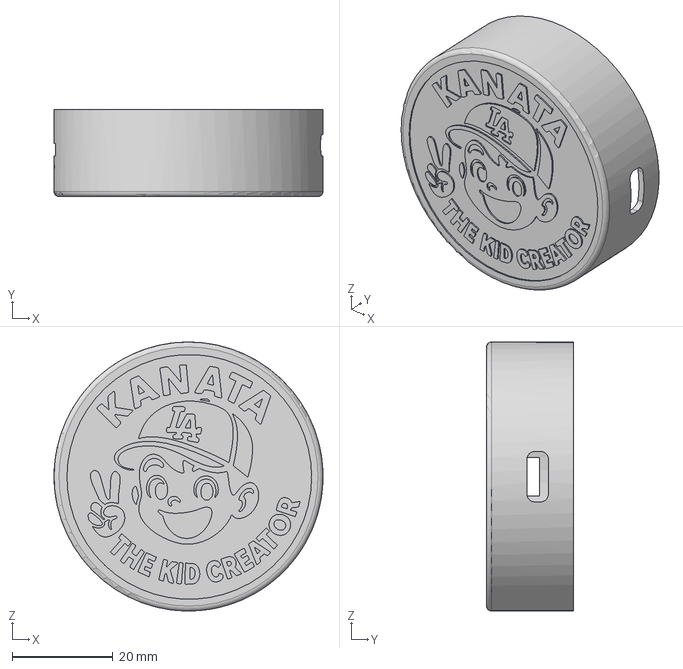
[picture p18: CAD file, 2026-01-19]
3d-models/button-speaker/button-speaker-bottom.step
53.5 x 17.3 x 53.5 mm

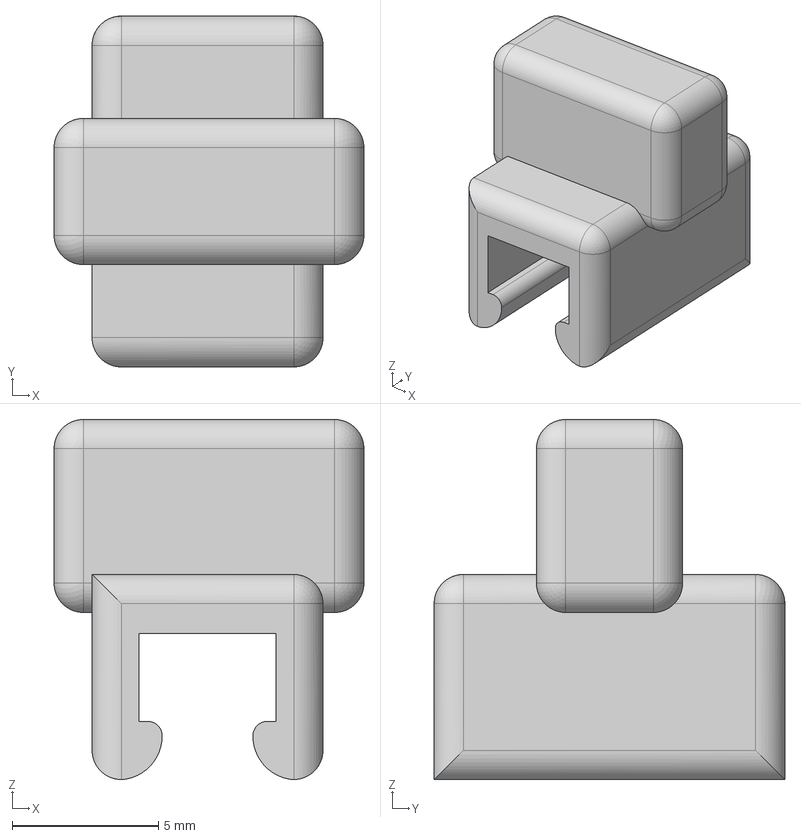
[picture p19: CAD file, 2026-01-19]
3d-models/bowtie-mic/bowtie-connector.step
10.6 x 12.0 x 12.3 mm

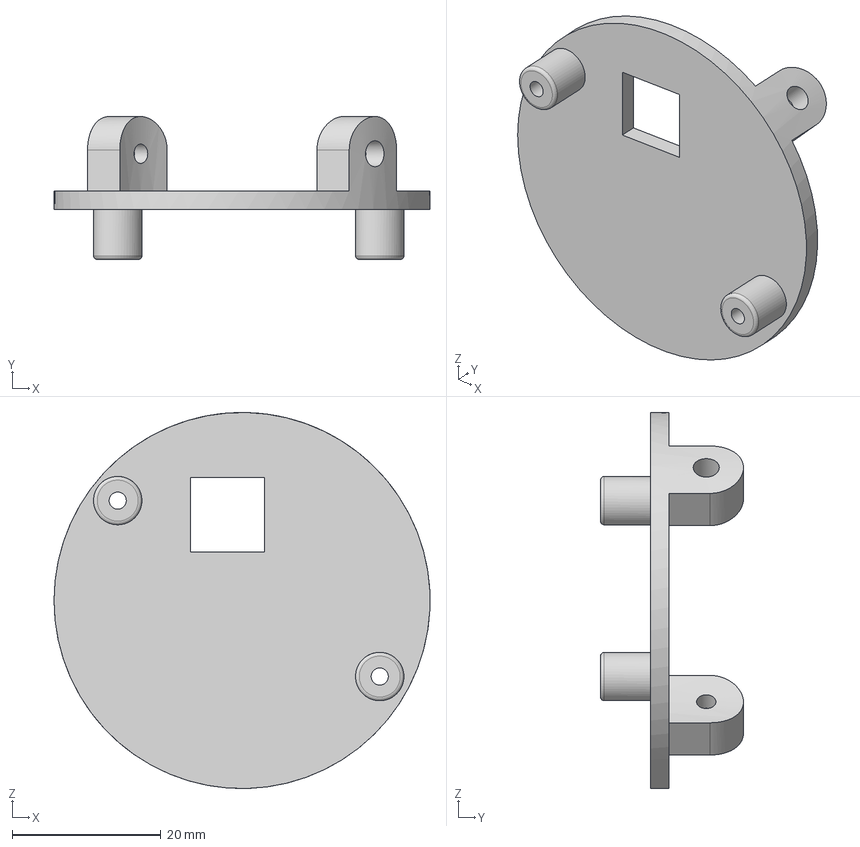
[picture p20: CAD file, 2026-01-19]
3d-models/button-speaker/button-speaker-top-big-speaker.step
50.5 x 19.2 x 50.5 mm

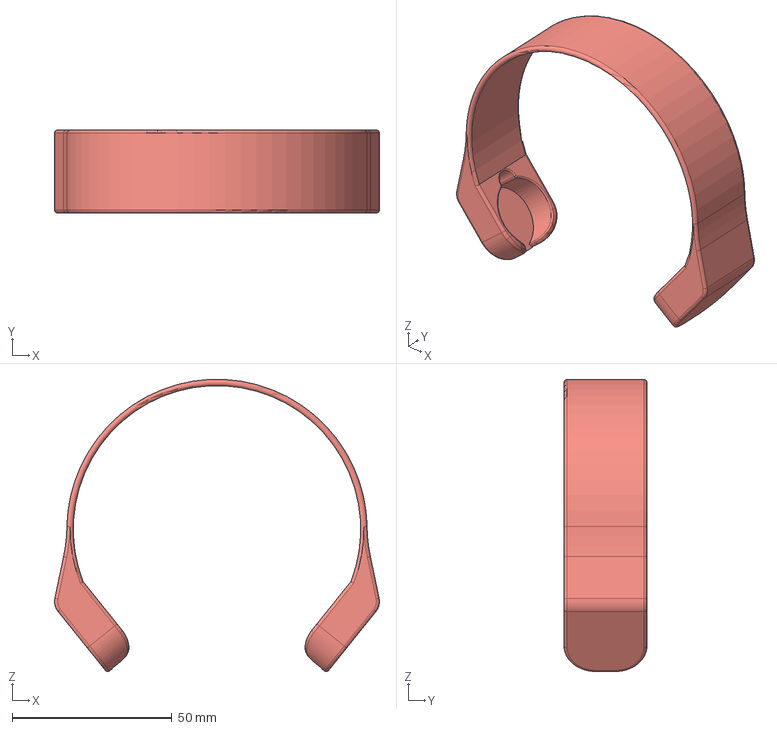
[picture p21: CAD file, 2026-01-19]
3d-models/bowtie-mic/bowtie-holder.step
101.8 x 26.0 x 91.5 mm

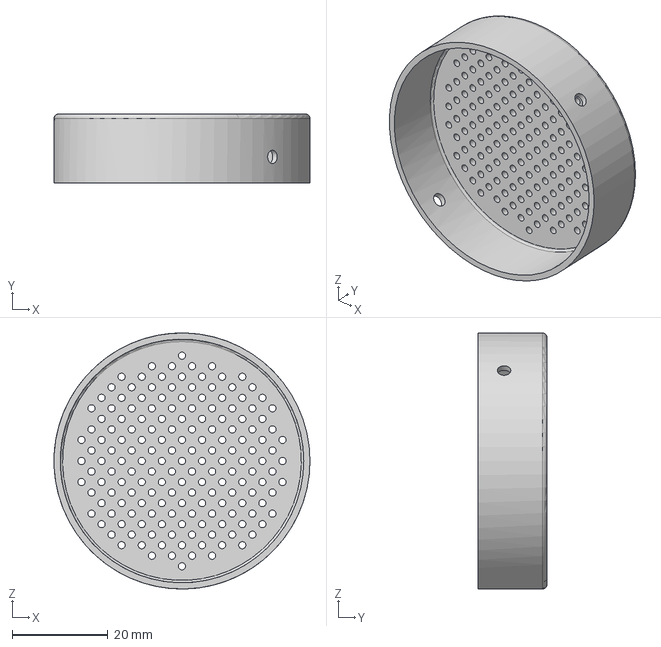
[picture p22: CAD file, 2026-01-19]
3d-models/button-speaker/button-speaker-top-cover.step
53.5 x 14.5 x 53.5 mm

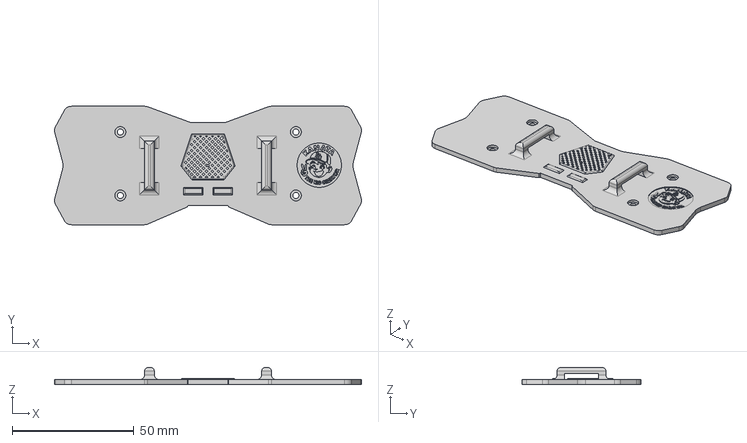
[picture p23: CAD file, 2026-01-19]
3d-models/bowtie-mic/red-bowtie-mic-bottom.step
125.9 x 48.6 x 7.00 mm

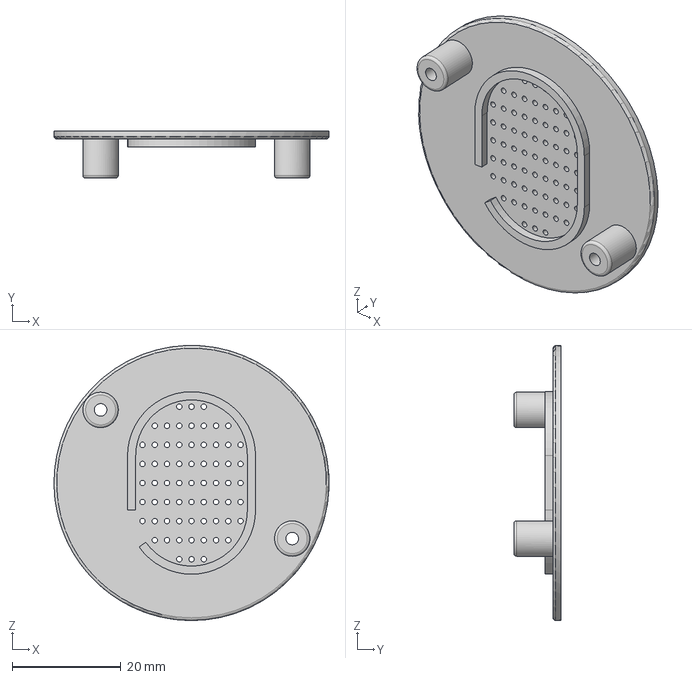
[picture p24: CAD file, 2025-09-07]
3d-models/button-speaker/button-speaker-top.step
50.5 x 8.70 x 50.5 mm

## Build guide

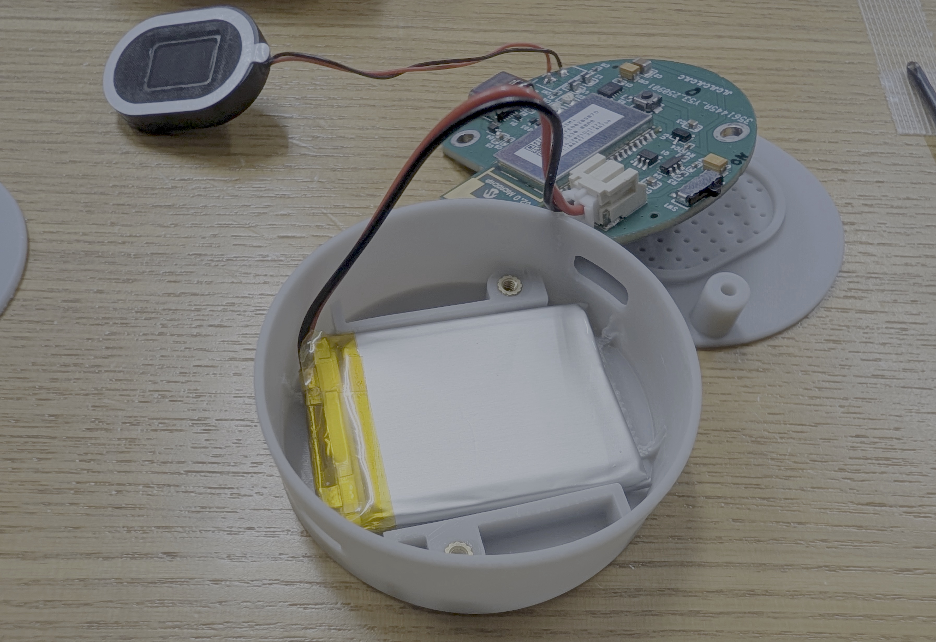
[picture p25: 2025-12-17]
images/button-speaker-assemble.jpg

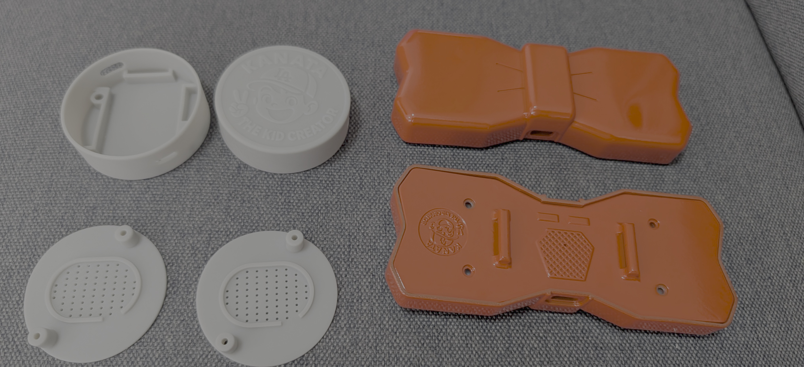
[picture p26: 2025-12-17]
images/3d-print.jpg

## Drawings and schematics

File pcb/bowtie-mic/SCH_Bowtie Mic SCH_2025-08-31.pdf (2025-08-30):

# MEMS PDM MIC (L) BM83 Bluetooth Mic (L only)

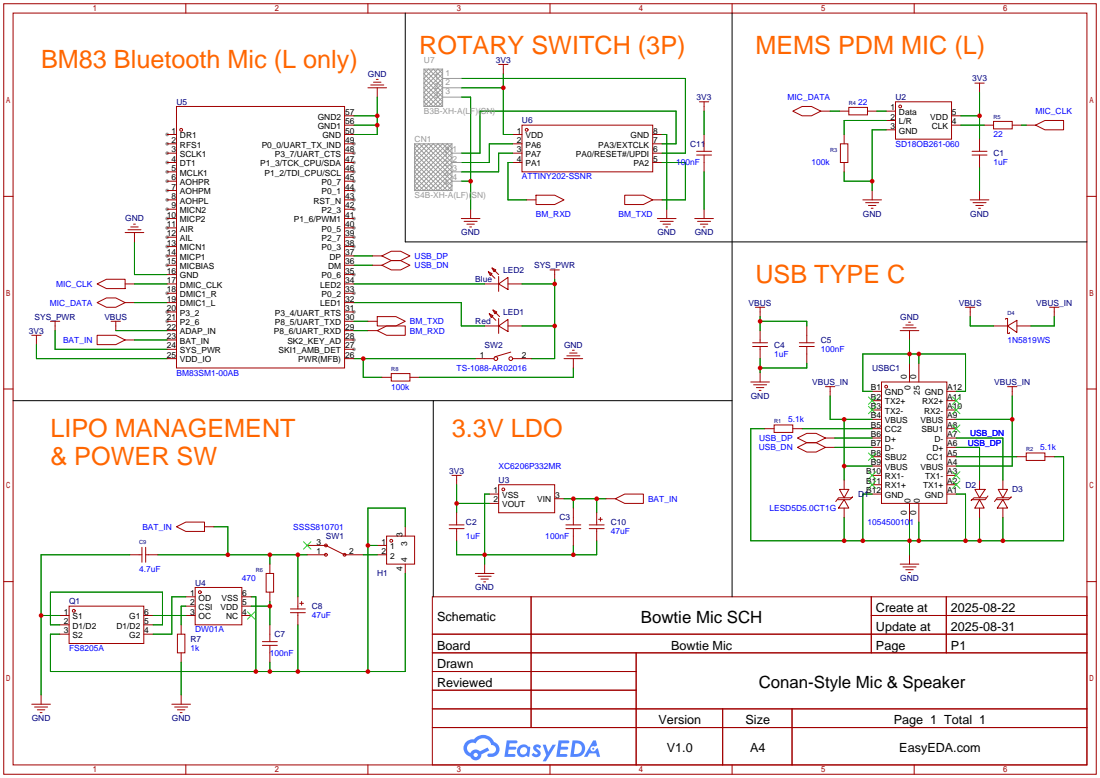
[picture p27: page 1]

GND A1 TX1+ A2 TX1- A3 VBUS A4 CC1 A5 D+ A6 D- A7 SBU1 A8 VBUS A9 RX2- A10 RX2+ A11 GND A12

Schematic | Bowtie Mic SCH | Create at | 2025-08-22

Update at | 2025-08-31

Board | Bowtie Mic | Page | P1
Drawn | | Conan-Style Mic & Speaker
Reviewed

Version | Size | Page 1 Total 1
V1.0 | A4 | EasyEDA.com

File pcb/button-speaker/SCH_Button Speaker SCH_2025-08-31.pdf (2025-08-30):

BM83 Bluetooth Speaker (L only) | Speaker Amp (Left)

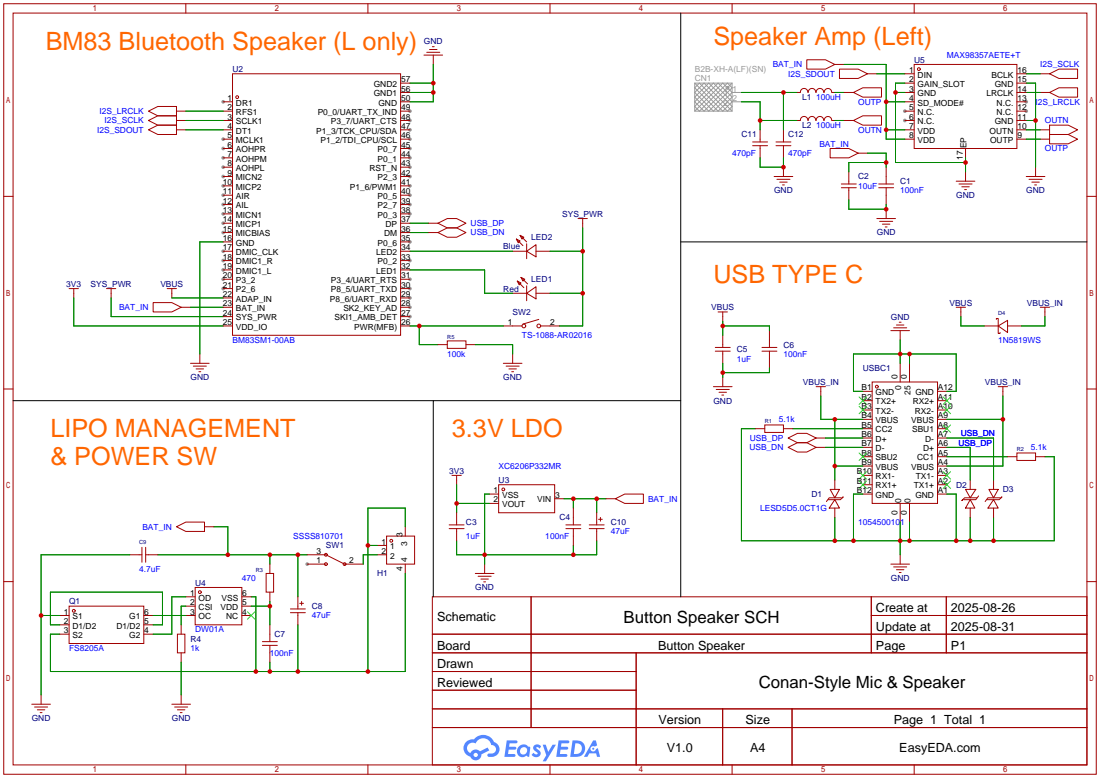
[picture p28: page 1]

OUTN 10 GND 11 N.C. 12 N.C. 13 LRCLK 14 GND 15 BCLK 16

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

Schematic | Button Speaker SCH | Create at | 2025-08-26

Update at | 2025-08-31

Board | Button Speaker | Page | P1
Drawn | | Conan-Style Mic & Speaker
Reviewed

Version | Size | Page 1 Total 1
V1.0 | A4 | EasyEDA.com

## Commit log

2025-08-30 Add pcb data
    [BOM_Bowtie Mic_Bowtie Mic SCH_2025-08-31.xlsx, BOM_Button Speaker_Button Speaker SCH_2025-08-31.xlsx, PickAndPlace_Bowtie Mic BRD_2025-08-31.xlsx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]
2025-08-30 Add schematic pdf
2025-09-07 Add 3d models of mic and speaker
    [button-speaker-bottom.step, button-speaker-top.step, red-bowtie-mic-bottom.step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]
2025-12-17 Add project documentation
    - README.md: Project overview and getting started
    - CLAUDE.md: Development guidelines for AI assistance
    - docs/concept.md: Project vision and architecture
    - docs/PLAN.md: Implementation roadmap for Jetson software
2025-12-17 Add PCB documentation with board images
2025-12-17 Fix image URLs in PCB README
2025-12-17 Update directory structure for 3d-models
    Reflect new subdirectory organization (bowtie-mic, button-speaker)
    [button-speaker-bottom.step, button-speaker-top.step, red-bowtie-mic-bottom.step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]
2025-12-17 Add 3D models documentation with assembly images
2025-12-17 Add hardware images to README
    - Hero image at the top
    - Bowtie mic PCB and case image
    - Button speaker PCB and case image
2025-12-17 Add Jetson Orin Nano Super setup scripts and documentation
    - Add bt-autoconnect.sh for automatic Bluetooth connection
    - Add systemd service for auto-connect on boot
    - Add README.md with setup instructions
    Closes #1
2025-12-17 Add Bluetooth device names and connection verification to README
    - Add Bluetooth names (RED_BOWTIE_MIC, BUTTON_SPEAKER) to device table
    - Add scan output example
    - Add pactl list sources short for verifying connection
    #1
2025-12-17 Add command to check current default audio devices
    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
2025-12-17 Add Python venv and ONNX Runtime GPU setup instructions
    - Python 3.10 venv with system-site-packages
    - ONNX Runtime GPU wheel from Jetson AI Lab
    - Verification command for GPU providers
    #2
2025-12-17 Add detailed PyTorch installation steps for Jetson
    - apt dependencies (python3-pip, libopenblas-dev)
    - cuSPARSELt installation
    - PyTorch wheel from NVIDIA
    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
2025-12-18 Simplify PyTorch installation with Jetson AI Lab index
    - Use pypi.jetson-ai-lab.io for torch 2.8.0 installation
    - Installs torch, torchvision, torchaudio in one command
    - Update version table to 2.8.0
    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
2026-01-19 Add step file of button-speaker for big speaker
    [bowtie-connector.step, bowtie-holder.step, button-speaker-bottom.step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]
2026-01-19 Replace Jetson to Raspberry Pi5
2026-01-22 docs: Add YouTube demo and OSHWLab PCB design links to README
    - Add demo video section with YouTube thumbnail
    - Add OSHWLab section for PCB design data
    - Update hero image to thumbnail-jlcpcb.jpg
